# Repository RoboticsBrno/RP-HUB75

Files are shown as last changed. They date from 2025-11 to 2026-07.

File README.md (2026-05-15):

# RP2350 HUB75 Driver

Deska pro řízení HUB75 displejů založená na čipu [RP2350](https://www.raspberrypi.com/documentation/microcontrollers/silicon.html#rp2350)

<div style="display:grid; grid-template-columns:repeat(auto-fit,minmax(160px,1fr)); gap:1rem; align-items:start;">
    <figure>
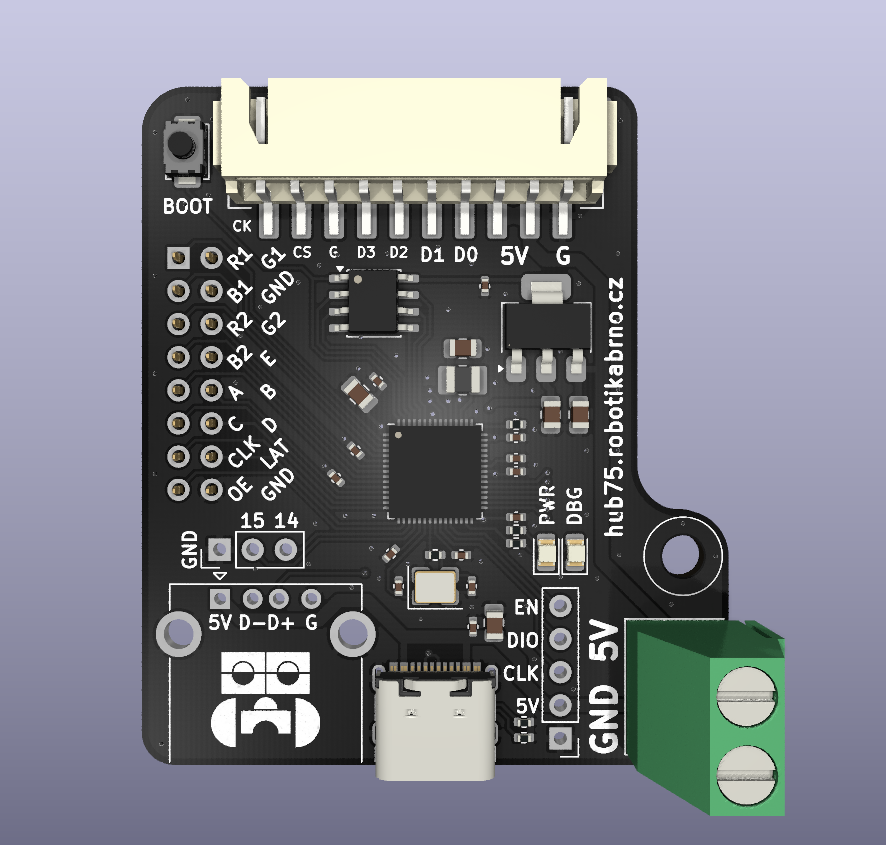
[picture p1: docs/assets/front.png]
Front pcb view
        
        <figcaption>Front</figcaption>
    </figure>
    <figure>
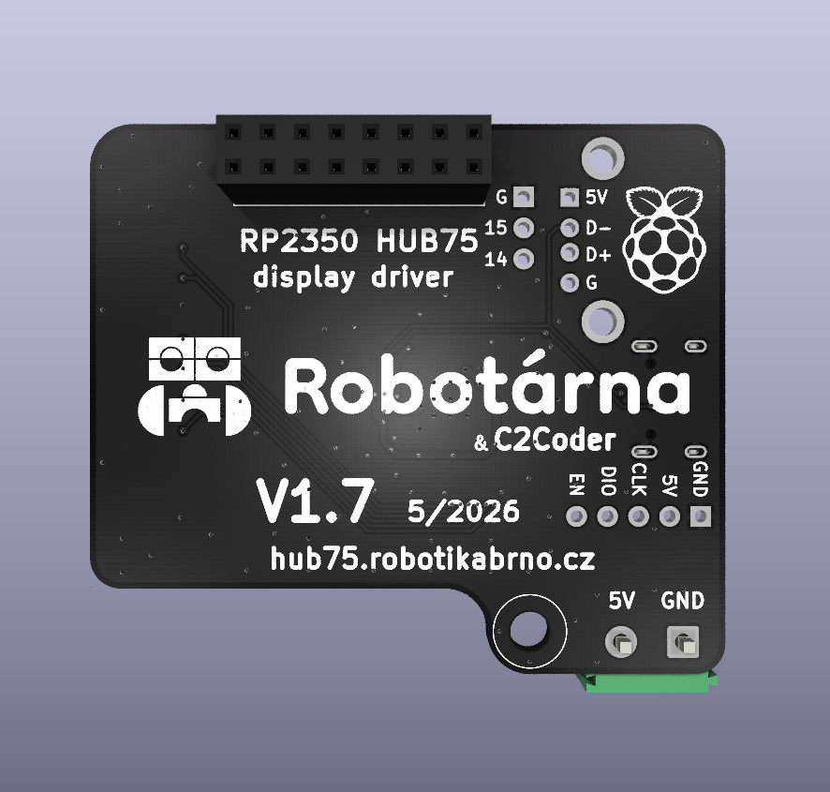
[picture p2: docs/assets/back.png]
Back pcb view
        
        <figcaption>Back</figcaption>
    </figure>
</div>

Firmware a jeho dokumentace může být nalezen ve složce `sw/fw`. Mini driver pro pužití displaje pomocí USB je ve složce `sw/rawd`.

## Pinout

### Displej

| RP2350 | Displej | Displej | RP2350 |
|---:|:---|---:|:---|
| IO0  | R1  | G1  | IO1  |
| IO2  | B1  | GND | GND  |
| IO3  | R2  | G2  | IO4  |
| IO5  | B2  | E | IO6  |
| IO7  | A | B | IO8  |
| IO9  | C | D | IO10 |
| IO11 | CLK | LAT | IO12 |
| IO13 | OE  | GND | GND  |

### Konektor

!!! note
    Je možno použít QSPI nebo SPI, v tom případě musí být TX na MISO/RX pinu master desky!
    
| Konektor (pin) | Signál | RP2350 |
|---:|---|:---|
| 1  | GND | GND  |
| 2  | 5V  | 5V |
| 3  | 5V  | 5V |
| 4  | D0  | IO19 |
| 5  | D1  | IO20 |
| 6  | D2  | IO21 |
| 7  | D3  | IO22 |
| 8  | GND | GND  |
| 9  | CS  | IO23 |
| 10 | CK  | IO24 |

### Extra konektor
- Na desce jsou vyvedené 2 extra datové piny na kterých je přístupné I2C a UART pro další rozšíření. (není implementováno)

| Pin | I2C | UART |
|---:|---|---|
| 14  | SDA  | TX  |
| 15  | SCL  | RX  |

### DBG & PWR Led
- Debug/status led - IO18
- Power led - 3V3

## Licence
Celý repositář je licencován pod MIT licencí s výjimkou složky `sw/fw`, která spadá pod licenci BSD-3-Clause.

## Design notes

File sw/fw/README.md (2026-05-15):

# Saturn Ring (RP-HUB75) Firmware

Firmware for the Saturn display driver board.

Currently, only USB CDC and QSPI (soon) are supported for video input. For more detailed info and the video protocol, see `src/proto.h`.

> [!note]
> To use the display board in the USB CDC mode, see `sw/rawd` for how to interact with it.

## Building

> [!note]
> You will need to have `pico-sdk` setup on your system and `PICO_SDK_PATH` must be properly exported.

To build the firmware package in the USB mode, execute:
```sh
cmake -B build/ . -G Ninja -DCMAKE_BUILD_TYPE=Release -DSR_INPUT_USB=ON
ninja -C build/
```

To flash, you can either enter the rp2350 bootsel and upload a u2f binary package located at `build/src/disp.uf2`.

Alternatively you can flash at any time using `picotool`:
```sh
picotool load build/src/disp.elf -fux
```

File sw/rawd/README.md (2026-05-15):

# Raw Display (rawd) helper

A minimal helper for outputing raw frames to the RP-HUB75 display over USB CDC.

It works by piping raw frames from an input file descriptor and inserting all required sync and config boilerplate into the output stream.
Tested on Linux and may possibly work on other unix derivitives like BSDs and Macs.

## Usage

The helper can be compiled directly by your system cc:
```sh
cd sw/rawd/
gcc -o rawd rawd.c
```

To use it, point the helper to the target CDC block device, the source file, source pixel format and target refresh rate:
```sh
# pipe a raw nv12 video file to the display
./rawd /dev/ttyACM0 vid.bin nv12 60

# pipe a rgb565 video stream from stdin
... | ./rawd /dev/ttyACM0 - rgb565 60
```

> [!warning]
> On linux, the ACM block devices are by default only accesible to the root. You will need to modify your udev rules to allow usage by a non-superuser.

## ffmpeg examples

Generating a raw video stream is not the most straigth forward thing, but `ffmpeg` makes it pretty simple.

> [!note]
> Some params might need to be modified for your setup. If ffmpeg is failing to start streaming, check if all block devices exist.

Play an input video using RGB888 at 60Hz:
```sh
ffmpeg -i [input file] -vcodec rawvideo -f rawvideo -vf "scale=64:64, format=rgb24" - | ./rawd /dev/ttyACM0 - rgb888 60
```

Play an input video rotated by 90° using NV12 at 60Hz:
```sh
ffmpeg -i [input file] -vcodec rawvideo -f rawvideo -vf "scale=64:64, transpose=1, format=nv12" - | ./rawd /dev/ttyACM0 - nv12 60
```

Play an input video with audio on the source PC (default output) at 60Hz: (Linux only)
```sh
ffmpeg -i [input file] -f alsa default -vcodec rawvideo -f rawvideo -vf "scale=64:64, transpose=1, format=nv12" - | ./rawd /dev/ttyACM0 - nv12 60
```

Capture desktop and stream to the display at 60Hz: (Linux **only**, requires root, AMD/Intel GPU only)
```sh
sudo ffmpeg -device /dev/dri/card1 -f kmsgrab -r 60 -i - -vf 'hwmap=derive_device=vaapi, scale_vaapi=w=128:h=128:format=nv12, hwdownload, format=nv12, scale=64:64, transpose=1' -vcodec rawvideo -f rawvideo - | ./rawd /dev/ttyACM0 - nv12 60
```

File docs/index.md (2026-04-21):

# RP2350 HUB75 Driver

Deska pro řízení HUB75 displejů založená na čipu [RP2350](https://www.raspberrypi.com/documentation/microcontrollers/silicon.html#rp2350)

<div style="display:grid; grid-template-columns:repeat(auto-fit,minmax(160px,1fr)); gap:1rem; align-items:start;">
    <figure>
        Přední strana
        <figcaption>Přední strana</figcaption>
    </figure>
    <figure>
        Zadní strana
        <figcaption>Zadní strana</figcaption>
    </figure>
</div>

## Pinout

### Displej

| RP2350 | Displej | Displej | RP2350 |
|---:|:---|---:|:---|
| IO0  | R1  | G1  | IO1 |
| IO2  | B1  | GND | GND |
| IO3  | R2  | G2  | IO4 |
| IO5  | B2  | E | IO6 |
| IO7  | A | B | IO8 |
| IO9  | C | D | IO10  |
| IO11 | CLK | LAT | IO12  |
| IO13 | OE  | GND | GND |

### Konektor

!!! note
    Je možno použít QSPI nebo SPI, v tom případě musí být TX na MISO/RX pinu master desky!

| Konektor (pin) | Signál | RP2350 |
|---:|---|:---|
| 1  | GND | GND  |
| 2  | 5V | 5V |
| 3  | 5V | 5V |
| 4  | D0 | IO19 |
| 5  | D1 | IO20 |
| 6  | D2 | IO21 |
| 7  | D3 | IO22 |
| 8  | GND | GND  |
| 9  | CS | IO23 |
| 10 | CK | IO24 |

### Extra konektor
- Na desce jsou vyvedené 2 extra datové piny na kterých je přístupné I2C a UART pro další rozšíření. (není implementováno)

| Pin | I2C | UART |
|---:|---|---|
| 14  | SDA  | TX  |
| 15  | SCL  | RX  |

### DBG & PWR Led
- Debug/status led - IO18
- Power led - 3V3

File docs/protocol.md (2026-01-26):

# Protocol

Board comunicates with the control board over SPI. 

Display board is **slave**, controling board is **host**,

## Command code

8-bit value determining the command

| Code | Description |
| --- | --- |
| 0x00 | Ignore |
| 0x0X | Ping |
| 0x1X | Screen |
| 0x2X | USB |

## Packet lenght

16-bit / uint16 number determining the lenght in bytes of the comming data (not including the command code or packet lenght)

**TODO** - little/big endian

## Data

Predetermined lenght of bytes representing what should be done / what happened. For example the display buffer or usb device feedback.

## Padding (optional)

Few bytes as a padding to make sure the recieving device recieves the correct amount of data

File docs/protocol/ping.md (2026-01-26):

# Ping

| Code | Description |
| --- | --- |
| 0x01 | Ping |
| 0x02 | Pong |

## Ping

### Request Format
```
[byte: 0x01]
```

Pings the connected device

### Response Format
```
[byte: 0x02]
```

Sends Pong back

## Pong

### Request Format
```
[byte: 0x02]
```

Recieves pong back confirming everything works

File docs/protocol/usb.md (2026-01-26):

# USB

| Code | Description |
| --- | --- |
| 0x20 | Get device data |

## Supported Device Types

- `0x00`: No device connected
- `0x01`: Keyboard
- `0x02`: Mouse
- `0x03`: Gamepad
- `0x04`: Mass Storage

## Get Device Data
### Request
Send **0x20** to pull queued USB reports from the attached device (only one device is supported).

### Response Format
```
[byte: 0x20] [uint16: packet_length] [byte: device_type] [byte: report_count] [reports...]
```

- `packet_length`: bytes following this field.
- `report_count`: number of reports included (0 when no data or no device).
### Device Data Formats

#### No Device (0x00)
`report_count` is 0; no additional bytes.

#### Keyboard (0x01)
Each report:
```
[byte: modifier_keys] [byte: reserved] [6 bytes: key_codes]
```

**Modifier Keys Flags:**
- Bit 0: Left Ctrl
- Bit 1: Left Shift
- Bit 2: Left Alt
- Bit 3: Left GUI (Windows/Command)
- Bit 4: Right Ctrl
- Bit 5: Right Shift
- Bit 6: Right Alt
- Bit 7: Right GUI

#### Mouse (0x02)
Each report:
```
[byte: buttons] [byte: x_movement] [byte: y_movement] [byte: wheel]
```

**Buttons:**
- Bit 0: Left button
- Bit 1: Right button
- Bit 2: Middle button
- Bits 3-7: Reserved

#### Gamepad (0x03)
Each report:
```
[byte: buttons] [byte: lt_analog] [byte: rt_analog] [byte: lx_analog] [byte: ly_analog] [byte: rx_analog] [byte: ry_analog]
```

**Buttons:**
- Bit 0: A / Cross
- Bit 1: B / Circle
- Bit 2: X / Square
- Bit 3: Y / Triangle
- Bit 4: LB / L1
- Bit 5: RB / R1
- Bit 6: Back / Select
- Bit 7: Start

#### Mass Storage (0x04)

**TODO**

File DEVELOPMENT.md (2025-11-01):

# Jak na vývoj

## Rozpoložení složek

```
RP-HUB75/
├── docs/    — MKdocs dokumentace
├── hw/      — Návrh desky - KiCad
└── sw/      — Software
     ├── fw/  — Firmware pro RP2350
     └── lib/ — Knihovna pro Jaculus
```

## Instalace nástrojů
Budeme potřebovat:
- `git`
- `python3` + `pip` (na Windows doporučuji z Win storu)

## Repo
Naklonujeme si repozitář:

```bash
git clone --recurse-submodules https://github.com/RoboticsBrno/RP-HUB75.git
```
nebo
```bash
git clone --recurse-submodules git@github.com:RoboticsBrno/RP-HUB75.git
```

## Konfigurace

Otevři projekt a v terminálu spusť:

pro linux a macos:
```bash
python3 -m venv .venv
source .venv/bin/activate
python3 -m pip install -r requirements.txt
```

pro windows CMD:
```bash
python3 -m venv .venv
./.venv/Scripts/Activate.bat
python3 -m pip install -r requirements.txt
```

pro windows Powershell:
```bash
python3 -m venv .venv
./.venv/Scripts/Activate.ps1
python3 -m pip install -r requirements.txt
```

## Znovu otevření už nainstalovaných toolů (vscode to někdy dělá sám)
pro linux a macos:
```bash
source .venv/bin/activate
```

pro windows CMD: 
```bash
./.venv/Scripts/Activate.bat
```

pro windows Powershell: 
```bash
./.venv/Scripts/Activate.ps1
```

## Práce s dokumentací

Lokální spuštění dokumentace:
 - `python3 -m mkdocs serve`

## Práce s obrázky

Obrázky přidávej do podsložek v `docs` podle adresy stránky, na které se mají zobrazit.
Uvnitř této stránky vytvoř složku `assets-large` a vlož do ní obrázky v plné velikosti.

Plugin [mkdocs-resize-images](https://github.com/JakubAndrysek/mkdocs-resize-images) automaticky rozpozná
změny v adresáři `assets-large` a při buildu zmenší obrázky do požadované velikosti a uloží je do složky `assets`.
Složka `assets-large` se neukládá do gitu, protože by byla zbytečně velká. Velké fotky si necháme jen lokálně a po dokončení návodu je můžete smazat.

Podporovené soubory jsou `.jpg`, `.jpeg`, `.png`, `.gif`, `.svg`.

## Vychytávky
Pro více rozjetých dokumentací je možné použít `--dev-addr 127.0.0.1:8001` pro specifikaci adresy a portu.

## Problémy s číslováním položek
Pokud se ti v dokumentaci nečíslují položky správně, zkus odsazovat položky mezi číselnými odrážkami pomocí tabulátoru. Například:
```markdown
1. První položka
    první text
2. Druhá položka
    druhý text
```
A ne: 
```markdown
1. První položka
první text
2. Druhá položka
druhý text
```
Některé editory to vrací vše na začátek!

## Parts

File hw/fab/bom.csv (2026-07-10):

Comment | Designator | Footprint | LCSC
ZD25WQ80CTIGT | U3 | Package_SO:SOIC-8_3.9x4.9mm_P1.27mm | C7525143
100n | C1,C2,C3,C5,C6,C7,C8,C9,C10,C16,C17 | Capacitor_SMD:C_0402_1005Metric | C1525
4.7u | C4,C11,C12,C13,C15 | Capacitor_SMD:C_0805_2012Metric | C1779
10p | C18,C19 | Capacitor_SMD:C_0402_1005Metric | C32949
USB_C_Receptacle_USB2.0_16P | J2 | Connector_USB:USB_C_Receptacle_G-Switch_GT-USB-7010ASV | C2988369
RP2350_60QFN | U2 | RP2350_60QFN_minimal:RP2350-QFN-60-1EP_7x7_P0.4mm_EP3.4x3.4mm_ThermalVias | C42411118
Screw_Terminal_01x02 | J3 | TerminalBlock_Phoenix:TerminalBlock_Phoenix_MKDS-1,5-2-5.08_1x02_P5.08mm_Horizontal | C8465
33 | R1 | Resistor_SMD:R_0402_1005Metric | C25105
LED | D1,D2 | LED_SMD:LED_0805_2012Metric | C84256
1k | R4,R5,R6 | Resistor_SMD:R_0402_1005Metric | C11702
5k1 | R2,R3 | Resistor_SMD:R_0402_1005Metric | C25905
SW_Push | SW1 | Button_Switch_SMD:SW_SPST_TS-1088-xR025 | C720477
Display Connector | J1 | Connector_PinSocket_2.54mm:PinSocket_2x08_P2.54mm_Vertical | C30734
3.3u | L1 | Inductor_SMD:L_1008_2520Metric_Pad1.43x2.20mm_HandSolder | C337916
TXM12M0004322CBCDO00T | Y1 | Crystal:Crystal_SMD_3225-4Pin_3.2x2.5mm | C362368
AMS1117-3.3 | U1 | Package_TO_SOT_SMD:SOT-223-3_TabPin2 | C6186
ZX-XH2.54-10PWT | J8 | Library:JST-XH-SMD-10Pin | C7429679

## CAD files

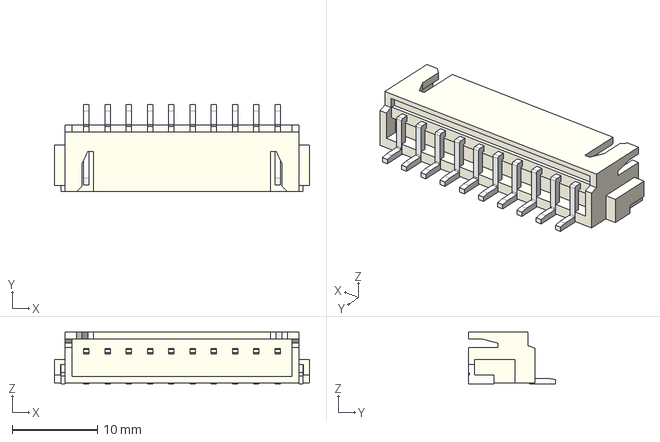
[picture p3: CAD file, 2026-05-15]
hw/JST-XH SMD 10p.step
30.0 x 10.2 x 6.10 mm

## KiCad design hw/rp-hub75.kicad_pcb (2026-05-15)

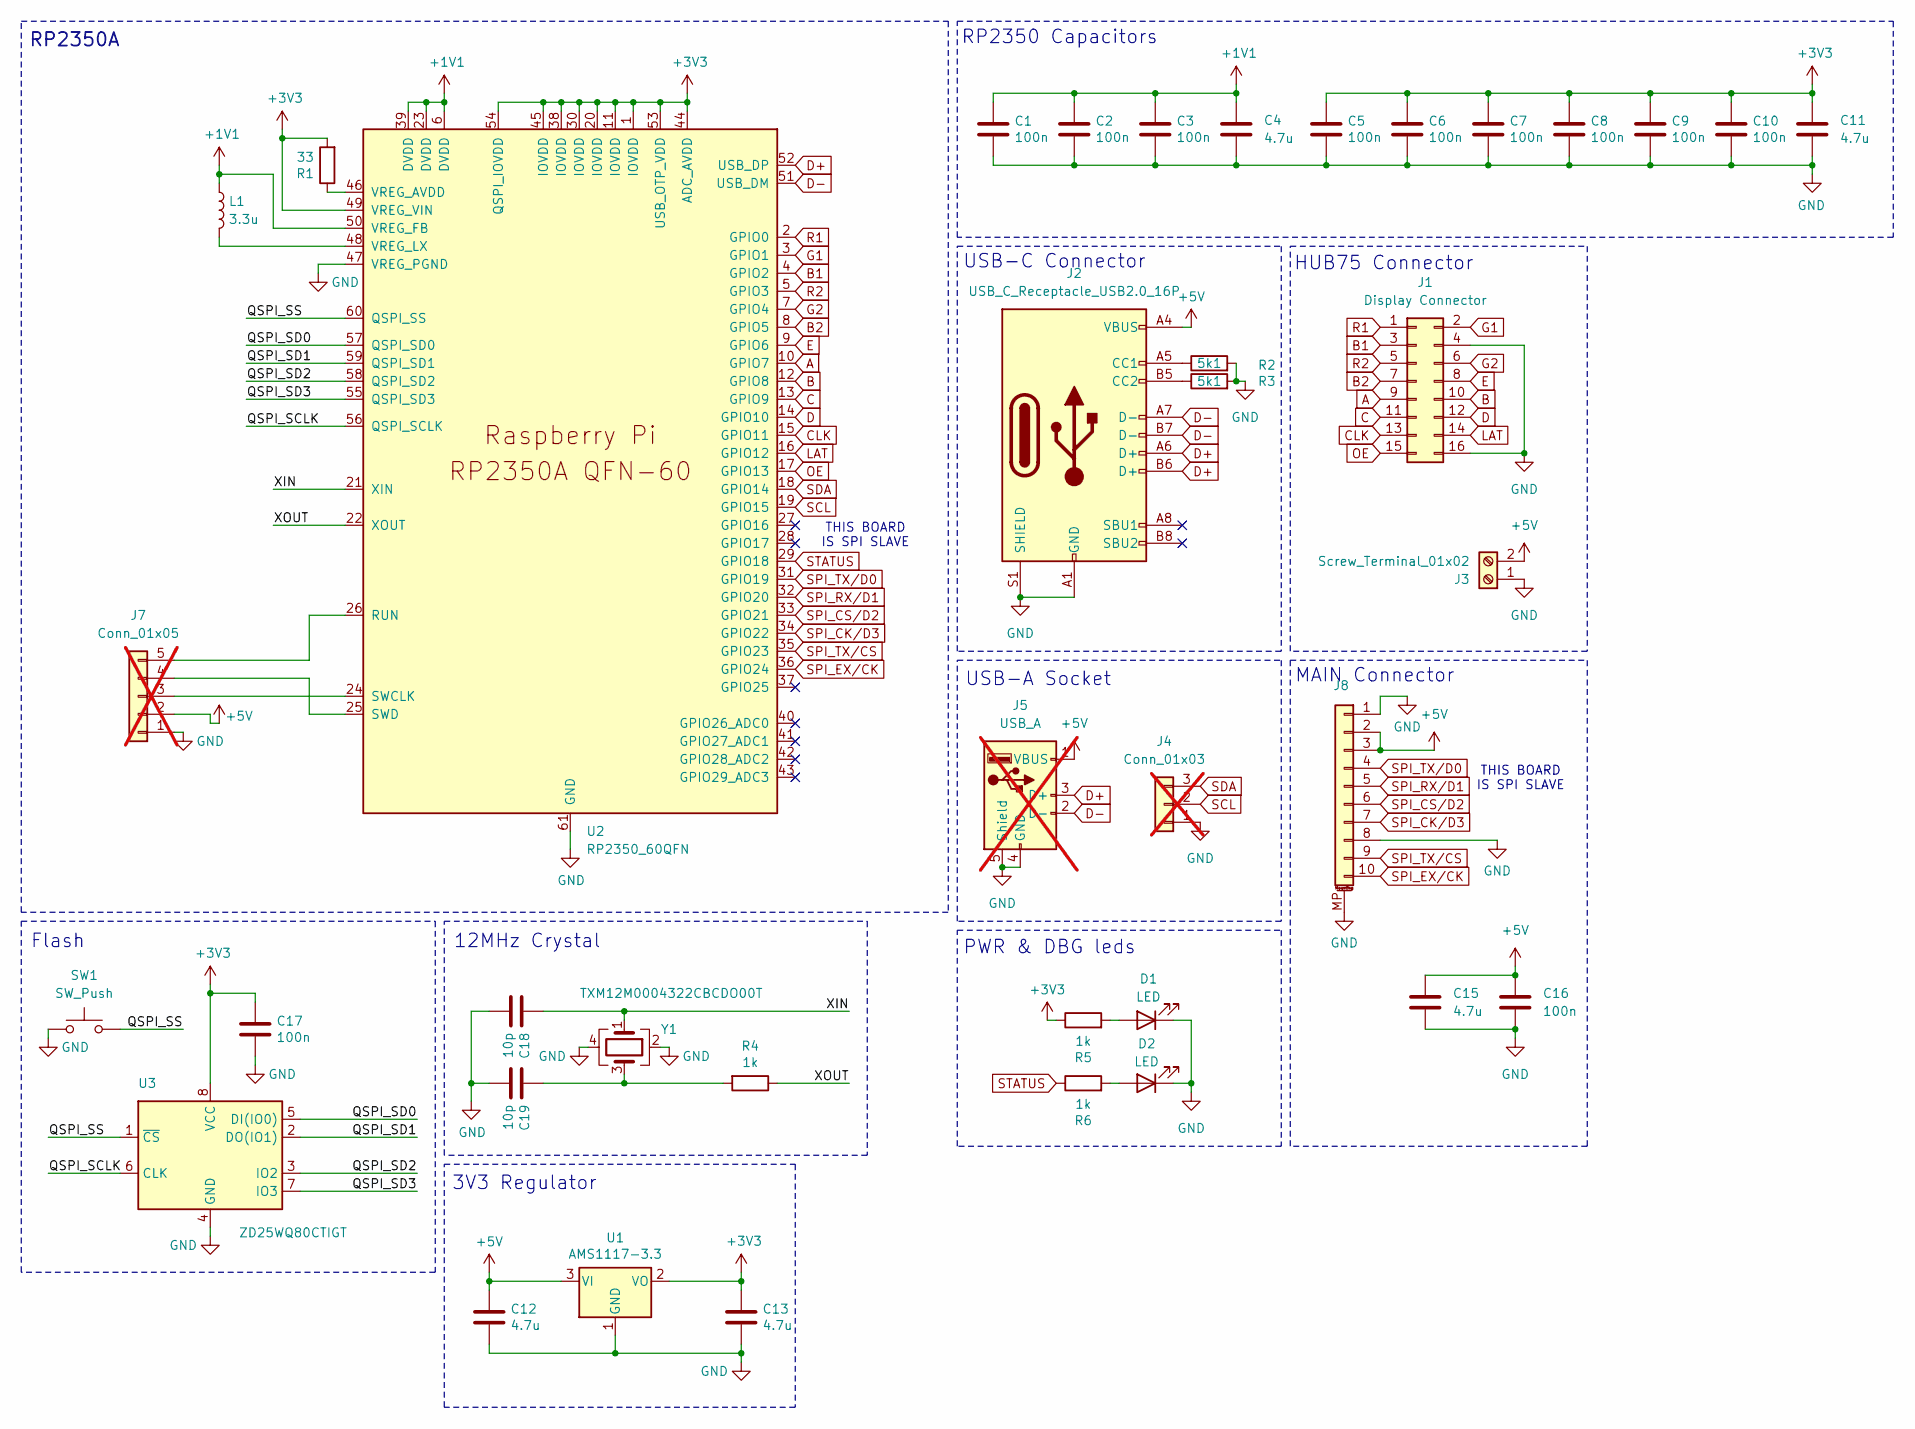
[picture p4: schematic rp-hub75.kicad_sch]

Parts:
C1, C2, C3, C5, C6, C7, C8, C9, C10, C16, C17: 100n; C_0402_1005Metric; LCSC C1525
C4, C11, C12, C13, C15: 4.7u; C_0805_2012Metric; LCSC C1779
C18, C19: 10p; C_0402_1005Metric; LCSC C32949
D1, D2: LED; LED_0805_2012Metric; LCSC C84256
J1: Display Connector; PinSocket_2x08_P2.54mm_Vertical; LCSC C30734
J2: USB_C_Receptacle_USB2.0_16P; USB_C_Receptacle_G-Switch_GT-USB-7010ASV; LCSC C2988369
J3: Screw_Terminal_01x02; TerminalBlock_Phoenix_MKDS-1,5-2-5.08_1x02_P5.08mm_Horizont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; LCSC C8465
J4: Conn_01x03; PinHeader_1x03_P2.54mm_Vertical; not fitted
J5: USB_A; USB_A_Kycon_KUSBX-AS1N-B_Horizontal; LCSC C2346; not fitted
J7: Conn_01x05; PinHeader_1x05_P2.54mm_Vertical; not fitted
J8: ZX-XH2.54-10PWT; JST-XH-SMD-10Pin; LCSC C7429679
L1: 3.3u; L_1008_2520Metric_Pad1.43x2.20mm_HandSolder; LCSC C337916
R1: 33; R_0402_1005Metric; LCSC C25105
R2, R3: 5k1; R_0402_1005Metric; LCSC C25905
R4, R5, R6: 1k; R_0402_1005Metric; LCSC C11702
SW1: SW_Push; SW_SPST_TS-1088-xR025; LCSC C720477
U1: AMS1117-3.3; SOT-223-3_TabPin2; LCSC C6186
U2: RP2350_60QFN; RP2350-QFN-60-1EP_7x7_P0.4mm_EP3.4x3.4mm_ThermalVias; LCSC C42411118
U3: ZD25WQ80CTIGT; SOIC-8_3.9x4.9mm_P1.27mm; LCSC C7525143
Y1: TXM12M0004322CBCDO00T; Crystal_SMD_3225-4Pin_3.2x2.5mm; LCSC C362368

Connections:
+1V1: C1.1, C2.1, C3.1, C4.1, L1.1, U2.6 (DVDD), U2.23 (DVDD), U2.39 (DVDD), U2.50 (VREG_FB)
+3V3: C5.1, C6.1, C7.1, C8.1, C9.1, C10.1, C11.1, C13.1, C17.1, R1.2, R5.1, U1.2 (VO), U2.1 (IOVDD), U2.11 (IOVDD), U2.20 (IOVDD), U2.30 (IOVDD), U2.38 (IOVDD), U2.44 (ADC_AVDD), U2.45 (IOVDD), U2.49 (VREG_VIN), U2.53 (USB_OTP_VDD), U2.54 (QSPI_IOVDD), U3.8 (VCC)
+5V: C12.1, C15.1, C16.1, J2.A4 (VBUS), J2.A9 (VBUS), J2.B4 (VBUS), J2.B9 (VBUS), J3.2, J5.1 (VBUS), J7.2, J8.2, J8.3, U1.3 (VI)
/QSPI_SCLK: U2.56 (QSPI_SCLK), U3.6 (CLK)
/QSPI_SD0: U2.57 (QSPI_SD0), U3.5 (DI(IO0))
/QSPI_SD1: U2.59 (QSPI_SD1), U3.2 (DO(IO1))
/QSPI_SD2: U2.58 (QSPI_SD2), U3.3 (IO2)
/QSPI_SD3: U2.55 (QSPI_SD3), U3.7 (IO3)
/QSPI_SS: SW1.2, U2.60 (QSPI_SS), U3.1 (~CS)
/XIN: C18.1, U2.21 (XIN), Y1.1
/XOUT: R4.1, U2.22 (XOUT)
A: J1.9, U2.10 (GPIO7)
B: J1.10, U2.12 (GPIO8)
B1: J1.3, U2.4 (GPIO2)
B2: J1.7, U2.8 (GPIO5)
C: J1.11, U2.13 (GPIO9)
CLK: J1.13, U2.15 (GPIO11)
D: J1.12, U2.14 (GPIO10)
D+: J2.A6 (D+), J2.B6 (D+), J5.3 (D+), U2.52 (USB_DP)
D-: J2.A7 (D-), J2.B7 (D-), J5.2 (D-), U2.51 (USB_DM)
E: J1.8, U2.9 (GPIO6)
G1: J1.2, U2.3 (GPIO1)
G2: J1.6, U2.7 (GPIO4)
GND: C1.2, C2.2, C3.2, C4.2, C5.2, C6.2, C7.2, C8.2, C9.2, C10.2, C11.2, C12.2, C13.2, C15.2, C16.2, C17.2, C18.2, C19.2, D1.1 (K), D2.1 (K), J1.4, J1.16, J2.A1 (GND), J2.A12 (GND), J2.B1 (GND), J2.B12 (GND), J2.S1 (SHIELD), J3.1, J4.1, J5.4 (GND), J5.5 (Shield), J7.1, J8.1, J8.8, J8.MP (MountPin), R2.2, R3.2, SW1.1, U1.1 (GND), U2.47 (VREG_PGND), U2.61 (GND), U3.4 (GND), Y1.2, Y1.4
LAT: J1.14, U2.16 (GPIO12)
unnamed: C19.1, R4.2, Y1.3
unnamed: D1.2 (A), R5.2
unnamed: D2.2 (A), R6.2
unnamed: J2.A5 (CC1), R2.1
unnamed: J2.B5 (CC2), R3.1
unnamed: J7.3, U2.24 (SWCLK)
unnamed: J7.4, U2.25 (SWD)
unnamed: J7.5, U2.26 (RUN)
unnamed: R1.1, U2.46 (VREG_AVDD)
unnamed: L1.2, U2.48 (VREG_LX)
OE: J1.15, U2.17 (GPIO13)
R1: J1.1, U2.2 (GPIO0)
R2: J1.5, U2.5 (GPIO3)
SCL: J4.2, U2.19 (GPIO15)
SDA: J4.3, U2.18 (GPIO14)
SPI_CK/D3: J8.7, U2.34 (GPIO22)
SPI_CS/D2: J8.6, U2.33 (GPIO21)
SPI_EX/CK: J8.10, U2.36 (GPIO24)
SPI_RX/D1: J8.5, U2.32 (GPIO20)
SPI_TX/CS: J8.9, U2.35 (GPIO23)
SPI_TX/D0: J8.4, U2.31 (GPIO19)
STATUS: R6.1, U2.29 (GPIO18)

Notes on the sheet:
THIS BOARD IS SPI SLAVE
HUB75 Connector
USB-A Socket
12MHz Crystal
PWR & DBG leds
USB-C Connector
3V3 Regulator
Flash
RP2350A
RP2350 Capacitors
MAIN Connector

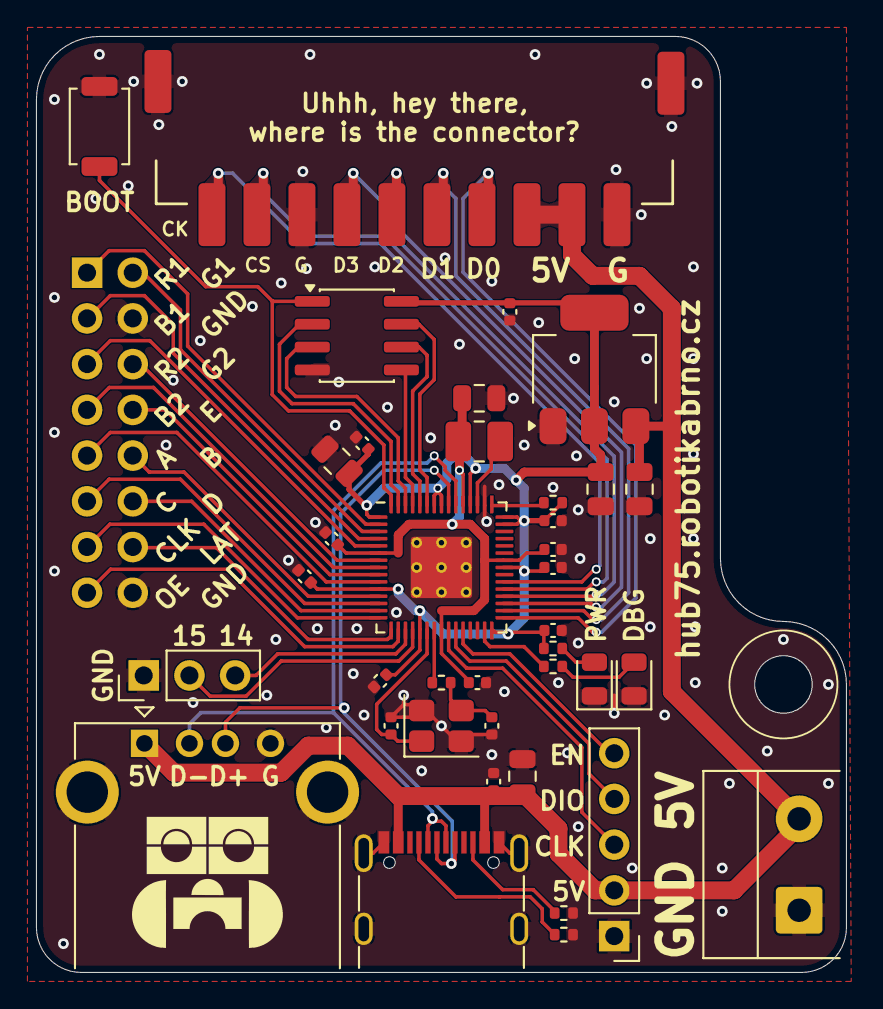
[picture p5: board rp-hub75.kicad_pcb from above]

Board: 2 copper layers, 45.0 x 52.0 mm, 39 parts (1 on the bottom side), 47 nets.

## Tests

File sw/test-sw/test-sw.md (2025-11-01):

# test-sw

esp-idf project testing the communication.

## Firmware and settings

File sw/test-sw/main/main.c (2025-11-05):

#include "freertos/FreeRTOS.h"
#include "freertos/task.h"
#include "driver/gpio.h"
#include "driver/adc.h"
#include "esp_log.h"
#include <stdio.h>
#include "esp_task_wdt.h"
#include <string.h>
#include "sdkconfig.h"

#include "rphub75.h"
#include "colors.h"

// Button pins for platformer controls
#define BUTTON_JUMP_GPIO 16  // Red button - Jump
#define BUTTON_RIGHT_GPIO 42 // Green button - Move Right
#define BUTTON_LEFT_GPIO 18  // Blue button - Move Left

// Platformer physics parameters
#define GRAVITY 100
#define PLAYER_JUMP_SPD 40.0f
#define PLAYER_HOR_SPD 20.0f
// Player structure
typedef struct
{
    float position_x;
    float position_y;
    float speed;
    bool canJump;
} Player;

// Environment item structure
typedef struct
{
    int x;
    int y;
    int width;
    int height;
} EnvItem;

// Global player instance
Player player = {32.0f, 20.0f, 0.0f, false};

// Environment items (platforms)
EnvItem envItems[] = {
    {0, 56, 64, 8},  // Ground platform
    {16, 44, 32, 4}, // Middle platform
    {8, 32, 16, 4},  // Left platform
    {40, 32, 16, 4}  // Right platform
};
int envItemsLength = sizeof(envItems) / sizeof(envItems[0]);

static const char *TAG = "RPHUB75";

rpio_rgb_t current_color = {255, 255, 255}; // Start with white
// Color increment value
#define COLOR_INCREMENT 32

esp_err_t initialize_buttons(void)
{
    ESP_LOGI(TAG, "Initializing buttons for platformer controls...");

    gpio_config_t button_config = {.pin_bit_mask = (1ULL << BUTTON_JUMP_GPIO) |
                                                   (1ULL << BUTTON_RIGHT_GPIO) |
                                                   (1ULL << BUTTON_LEFT_GPIO),
                                   .mode = GPIO_MODE_INPUT,
                                   .pull_up_en = GPIO_PULLUP_ENABLE,
                                   .pull_down_en = GPIO_PULLDOWN_DISABLE,
                                   .intr_type = GPIO_INTR_DISABLE};

    esp_err_t ret = gpio_config(&button_config);
    if (ret != ESP_OK)
    {
        ESP_LOGE(TAG, "Failed to configure buttons: 0x%x", ret);
        return ret;
    }

    ESP_LOGI(
        TAG,
        "Buttons initialized: Jump(GPIO %d), Right(GPIO %d), Left(GPIO %d)",
        BUTTON_JUMP_GPIO, BUTTON_RIGHT_GPIO, BUTTON_LEFT_GPIO);

    return ESP_OK;
}

void update_player(Player *player, EnvItem *envItems, int envItemsLength,
                   float delta)
{
    // Read button states
    bool leftPressed = (gpio_get_level(BUTTON_LEFT_GPIO) == 0);
    bool rightPressed = (gpio_get_level(BUTTON_RIGHT_GPIO) == 0);
    bool jumpPressed = (gpio_get_level(BUTTON_JUMP_GPIO) == 0);

    // Horizontal movement
    if (leftPressed)
        player->position_x -= PLAYER_HOR_SPD * delta;
    if (rightPressed)
        player->position_x += PLAYER_HOR_SPD * delta;

    // Jumping
    if (jumpPressed && player->canJump)
    {
        player->speed = -PLAYER_JUMP_SPD;
        player->canJump = false;
    }

    // Apply gravity and check collisions
    bool hitObstacle = false;

    // Temporary position for collision checking
    float new_y = player->position_y + player->speed * delta;

    for (int i = 0; i < envItemsLength; i++)
    {
        EnvItem *ei = &envItems[i];

        // Check if player would collide with this platform
        // Player is 8x8 pixels, positioned at center-bottom
        float player_left = player->position_x - 4;
        float player_right = player->position_x + 4;
        float player_bottom = new_y + 4; // Bottom of player

        // Platform bounds
        float platform_left = ei->x;
        float platform_right = ei->x + ei->width;
        float platform_top = ei->y;

        // Check if player is above platform and falling onto it
        if (player_bottom >= platform_top &&
            player->position_y + 4 <= platform_top && // Was above platform
            player_right > platform_left && player_left < platform_right &&
            player->speed >= 0)
        { // Only check when falling

            hitObstacle = true;
            player->speed = 0.0f;
            player->position_y =
                platform_top - 4; // Position player on top of platform
            break;
        }
    }

    if (!hitObstacle)
    {
        player->position_y = new_y;
        player->speed += GRAVITY * delta;
        player->canJump = false;
    }
    else
    {
        player->canJump = true;
    }

    // Keep player within screen bounds
    if (player->position_x < 4)
        player->position_x = 4;
    if (player->position_x > RP_HUB75_WIDTH - 4)
        player->position_x = RP_HUB75_WIDTH - 4;
    if (player->position_y > RP_HUB75_HEIGHT - 4)
    {
        player->position_y = RP_HUB75_HEIGHT - 4;
        player->speed = 0;
        player->canJump = true;
    }
}

void draw_rectangle(rpio_rgb_t *fb, int x, int y, int width, int height,
                    uint8_t r, uint8_t g, uint8_t b)
{
    for (int py = y; py < y + height && py < RP_HUB75_HEIGHT; py++)
    {
        for (int px = x; px < x + width && px < RP_HUB75_WIDTH; px++)
        {
            if (px >= 0 && py >= 0)
            {
                int index = py * RP_HUB75_WIDTH + px;
                fb[index].r = r;
                fb[index].g = g;
                fb[index].b = b;
            }
        }
    }
}

void update_framebuffer(rpio_rgb_t *fb, Player *player, EnvItem *envItems,
                        int envItemsLength)
{
    // Clear framebuffer (transparent/black background)
    memset(fb, 0, sizeof(rpio_rgb_t) * RP_HUB75_WIDTH * RP_HUB75_HEIGHT);

    // Draw platforms (gray)
    for (int i = 0; i < envItemsLength; i++)
    {
        draw_rectangle(fb, envItems[i].x, envItems[i].y, envItems[i].width,
                       envItems[i].height, 128, 128, 128); // Gray color
    }

    // Draw player (red) - 8x8 pixels centered at player position
    int player_x = (int)player->position_x - 4;
    int player_y = (int)player->position_y - 4;
    draw_rectangle(fb, player_x, player_y, 8, 8, 255, 0, 0); // Red color
}
esp_err_t ret;

void app_main(void)
{
    ESP_LOGI(TAG, "Starting RPHUB75 example");
    spi_init();
    spi_set_internal_rx_capacity(0);
    // Initialize ADC for potentiometers
    // Initialize buttons for platformer controls
    ret = initialize_buttons();
    if (ret != ESP_OK)
    {
        return;
    }
    size_t buffer_size = (size_t)RP_HUB75_WIDTH * (size_t)RP_HUB75_HEIGHT * sizeof(rpio_rgb_t);
    rpio_rgb_t *buffer = pvPortMalloc(buffer_size);
    if (buffer == NULL)
    {
        ESP_LOGE(TAG, "Failed to allocate %zu bytes for framebuffer", buffer_size);
        while (1)
        {
            vTaskDelay(portMAX_DELAY);
        }
    }
    for (int i = 0; i < buffer_size / sizeof(rpio_rgb_t); i++)
    {
        buffer[i] = color_black;
    }
    TickType_t last_frame_time = xTaskGetTickCount();
    const TickType_t frame_delay = pdMS_TO_TICKS(16); // ~60 FPS
    int frame_counter = 0;

    {
        esp_err_t wdt_ret = esp_task_wdt_add(NULL);
        if (wdt_ret != ESP_OK)
        {
            ESP_LOGW(TAG, "esp_task_wdt_add returned 0x%x", wdt_ret);
        }
    }
    while (1)
    {
        TickType_t current_time = xTaskGetTickCount();
        float delta_time = (float)(current_time - last_frame_time) *
                           portTICK_PERIOD_MS / 1000.0f;
        last_frame_time = current_time;
        frame_counter++;

        update_player(&player, envItems, envItemsLength, delta_time);

        update_framebuffer(buffer, &player, envItems, envItemsLength);

        spi_send_data((uint8_t *)buffer,
                      RP_HUB75_WIDTH * RP_HUB75_HEIGHT * sizeof(rpio_rgb_t));
    }
}

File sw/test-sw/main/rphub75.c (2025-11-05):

// rpio.c
// SPI initialization implementation that uses pin definitions from ../rphub75.h

#include "esp_log.h"
#include <stdio.h>
#include "sdkconfig.h"
#include "driver/spi_master.h"
#include "driver/gpio.h"
#include "esp_err.h"
#include "esp_mac.h"
#include <stdint.h>
#include <math.h>
#include <stdlib.h>
#include <string.h>
#include <limits.h>
#include "freertos/FreeRTOS.h"
#include "freertos/semphr.h"
#include "freertos/task.h"
#include "esp_task_wdt.h"
#include "esp_heap_caps.h"

#include "rphub75.h"

static const char *TAG = "RPHUB75";
static spi_device_handle_t s_spi = NULL;
static SemaphoreHandle_t s_spi_lock = NULL;

/* Internal RX storage for polling-style reads. */
static uint8_t *s_internal_rx = NULL;
static size_t s_internal_rx_capacity = 0;
static size_t s_internal_rx_len = 0;

static inline float clampf(float val, float min, float max)
{
    return fminf(fmaxf(val, min), max);
}

// Color creation functions
rpio_rgb_t rgb(uint8_t r, uint8_t g, uint8_t b)
{
    rpio_rgb_t color = {.r = r, .g = g, .b = b};
    return color;
}

rpio_rgb_t rgba(uint8_t r, uint8_t g, uint8_t b, float a)
{
    rpio_rgb_t color = {.r = (uint8_t)roundf(clampf(r * a, 0.0f, 255.0f)), .g = (uint8_t)roundf(clampf(g * a, 0.0f, 255.0f)), .b = (uint8_t)roundf(clampf(b * a, 0.0f, 255.0f))};
    return color;
}

rpio_rgb_t hsv(uint8_t h, uint8_t s, uint8_t v)
{
    uint8_t region = h / 43;
    uint8_t remainder = (h - (region * 43)) * 6;

    uint8_t p = (v * (255 - s)) >> 8;
    uint8_t q = (v * (255 - ((s * remainder) >> 8))) >> 8;
    uint8_t t = (v * (255 - ((s * (255 - remainder)) >> 8))) >> 8;

    rpio_rgb_t color;
    switch (region)
    {
    case 0:
        color.r = v;
        color.g = t;
        color.b = p;
        break;
    case 1:
        color.r = q;
        color.g = v;
        color.b = p;
        break;
    case 2:
        color.r = p;
        color.g = v;
        color.b = t;
        break;
    case 3:
        color.r = p;
        color.g = q;
        color.b = v;
        break;
    case 4:
        color.r = t;
        color.g = p;
        color.b = v;
        break;
    default:
        color.r = v;
        color.g = p;
        color.b = q;
        break;
    }
    return color;
}

// SPI functions

esp_err_t spi_init(void)
{
    esp_log_level_set(TAG, ESP_LOG_INFO);

    spi_bus_config_t buscfg = {
        .miso_io_num = RP_PIN_MISO,
        .mosi_io_num = RP_PIN_MOSI,
        .sclk_io_num = RP_PIN_SCLK,

        .max_transfer_sz = 4096, // use default
        .flags = 0,
        .intr_flags = 0};

    // Initialize SPI bus
    esp_err_t ret = spi_bus_initialize(SPI_HOST, &buscfg, SPI_DMA_CH_AUTO);
    if (ret != ESP_OK)
    {
        ESP_LOGE(TAG, "Failed to initialize SPI bus: 0x%x", ret);
        return ret;
    }

    ESP_LOGI(TAG, "SPI bus initialized successfully");
    ESP_LOGI(TAG, "Adding SPI device...");

    spi_device_interface_config_t devcfg = {
        .command_bits = 0,
        .address_bits = 0,
        .dummy_bits = 0,
        .mode = 0, // SPI mode 0
        .duty_cycle_pos = 0,
        .cs_ena_pretrans = 0,
        .cs_ena_posttrans = 0,
        .clock_speed_hz = 20 * 1000 * 1000, // 20 MHz
        .input_delay_ns = 0,
        .spics_io_num = RP_PIN_CS,
        .flags = 0,
        .queue_size = 3,
        .pre_cb = NULL,
        .post_cb = NULL};

    ret = spi_bus_add_device(SPI_HOST, &devcfg, &s_spi);
    if (ret != ESP_OK)
    {
        ESP_LOGE(TAG, "Failed to add SPI device: 0x%x", ret);
        spi_bus_free(SPI_HOST);
        return ret;
    }

    /* create mutex for SPI operations */
    if (s_spi_lock == NULL)
    {
        s_spi_lock = xSemaphoreCreateMutex();
        if (s_spi_lock == NULL)
        {
            ESP_LOGW(TAG, "Failed to create spi mutex");
        }
    }

    ESP_LOGI(TAG, "SPI device added successfully");
    return ESP_OK;
}

esp_err_t spi_send_and_receive(const uint8_t *tx, uint32_t tx_len, uint8_t *rx, uint32_t rx_len)
{
    ESP_LOGI(TAG, "spi_send_and_receive: start");
    if (s_spi == NULL)
    {
        ESP_LOGI(TAG, "spi_send_and_receive: err");
        return ESP_ERR_INVALID_STATE;
    }

    esp_err_t ret = ESP_OK;

    if (s_spi_lock)
        xSemaphoreTake(s_spi_lock, portMAX_DELAY);

    uint32_t total = tx_len;
    if (rx_len > total)
        total = rx_len;

    for (uint32_t i = 0; i < total; ++i)
    {
        if (i%1000 == 0){

            esp_err_t wdt_ret = esp_task_wdt_reset();
            if (wdt_ret != ESP_OK)
            {
                ESP_LOGW(TAG, "esp_task_wdt_reset returned 0x%x", wdt_ret);
            }
            /* brief yield so the idle task can run and reset the idle WDT
             * (prevents "IDLE0 task did not reset watchdog" when large
             *  transfers monopolize CPU). Use a 1-tick delay which is
             *  short but gives the scheduler a chance to run lower
             *  priority tasks (including IDLE). */
            vTaskDelay(1);
        }

        uint8_t tx_byte = 0x00;
        if (tx != NULL && i < tx_len)
            tx_byte = tx[i];

        uint8_t rx_byte = 0x00;

        spi_transaction_t t = {0};
        t.length = 8; // bits (one byte)
        t.tx_buffer = &tx_byte;
        t.rxlength = 8;
        t.rx_buffer = &rx_byte;

        ret = spi_device_queue_trans(s_spi, &t, portMAX_DELAY);

        if (ret != ESP_OK)
        {
            ESP_LOGE(TAG, "spi_send_and_receive: byte %lu transmit failed: %s", (unsigned long)i, esp_err_to_name(ret));
            break;
        }

        if (rx != NULL && i < rx_len)
            rx[i] = rx_byte;
    }

    if (s_spi_lock)
        xSemaphoreGive(s_spi_lock);
    ESP_LOGI(TAG, "spi_send_and_receive: end");
    return ret;
}

esp_err_t spi_set_internal_rx_capacity(uint32_t capacity)
{
    if (capacity == 0)
    {
        if (s_internal_rx)
        {
            heap_caps_free(s_internal_rx);
            s_internal_rx = NULL;
        }
        s_internal_rx_capacity = 0;
        s_internal_rx_len = 0;
        return ESP_OK;
    }

    uint8_t *buf = heap_caps_calloc(capacity, 1, MALLOC_CAP_DMA);
    if (buf == NULL)
        return ESP_ERR_NO_MEM;

    // replace existing buffer
    if (s_internal_rx)
        heap_caps_free(s_internal_rx);
    s_internal_rx = buf;
    s_internal_rx_capacity = capacity;
    s_internal_rx_len = 0;
    return ESP_OK;
}

const uint8_t *spi_get_last_rx(uint32_t *out_len)
{
    if (out_len)
        *out_len = s_internal_rx_len;
    return s_internal_rx;
}

esp_err_t spi_send_data(const uint8_t *tx, uint32_t tx_len)
{
    ESP_LOGI(TAG, "spi_send_data: tx_len=%u", (unsigned)tx_len);
    if (s_internal_rx_capacity == 0)
    {
        return spi_send_and_receive(tx, tx_len, NULL, 0);
    }
    esp_err_t ret = spi_send_and_receive(tx, tx_len, s_internal_rx, s_internal_rx_capacity);
    if (ret == ESP_OK)
    {
        s_internal_rx_len = s_internal_rx_capacity;
    }
    return ret;
}
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

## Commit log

2025-11-01 hw: edit DBG connector, new capacitor
    [rp-hub75.kicad_pcb, rp-hub75.kicad_sch]
2026-01-25 fix: schematic cleanup
    [rp-hub75.kicad_sch]
2026-02-13 v1.5 - use QSPI, better 1V1 line
    [rp-hub75.kicad_pcb, rp-hub75.kicad_sch]
2026-04-09 fw: initial driver firmware
2026-04-09 fw: WIP frame sync and lfsr sequence gen
2026-04-15 sw/rawd: add `rawd` driver for pc usage
2026-04-15 fw: add initial qspi rx driver
2026-07-10 panel created
    [bom.csv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]
